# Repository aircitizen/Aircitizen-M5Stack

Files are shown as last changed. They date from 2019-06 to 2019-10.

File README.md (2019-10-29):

# m5stack

### Description

Here you'll find the CAD (STL+ F3d) for making your own shield, and the electronic shield (eagle + gerber file)

Component Name | Product link
------------ | -------------
M5 board |  https://amzn.to/2YmzmEy
Battery shield 700mAh  | https://amzn.to/2IX5oBG
Plantower PMSA003 | add link here.

 ###### Credit
Created by Vincent DUPUIS
with participation of :

Adel KHENICHE on Electronic production

Raphael BOYERO on 3D design.

#### Sources

Adafruit SHT31 | https://github.com/adafruit/Adafruit-SHT31-Sensor-Breakout-PCB

Adafruit Si7021 | https://learn.adafruit.com/adafruit-si7021-temperature-plus-humidity-sensor

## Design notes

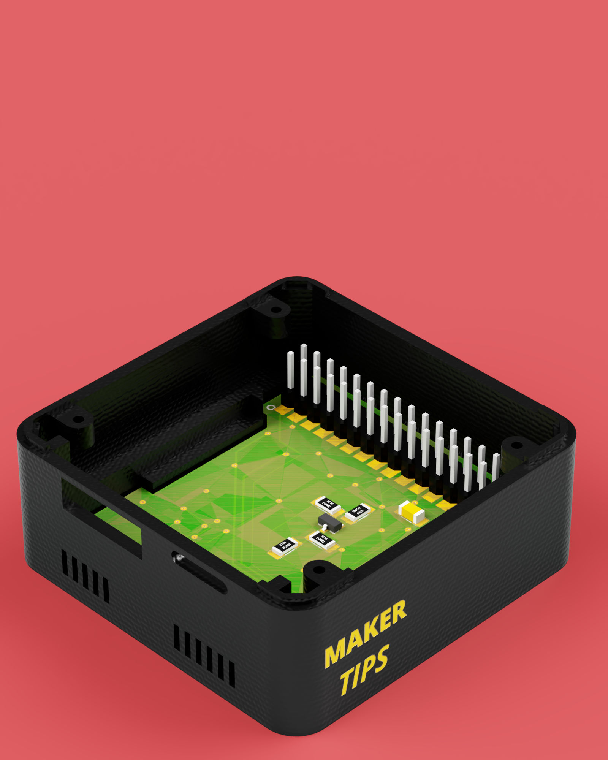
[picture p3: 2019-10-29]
SHIELDM5AIRCITIZEN_PROD_SANS_FOND_2019-Jul-20_07-20-32PM-000_CustomizedView6140740937.png

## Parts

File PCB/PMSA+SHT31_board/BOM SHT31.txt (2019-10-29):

Partlist exported from C:/Users/adelk/Documents/aircitizen2/Aircitizen-M5Stack/PCB/PMSA+SHT31_board/SHT31_2.sch at 15/07/2019 10:04

Part Value                 Device                Package     Description                                                             DK_ID          PROD_ID     P_NAME
C2   10uF                  CAP_CERAMIC_1206      _1206       Ceramic Capacitors                                                                                       
C13  10uF                  RES-US1206FAB         R1206FAB    Resistor (US Symbol)                                                                   CAP-11330         
CN2  CON_PINHD-2X15        CON_PINHD-2X15        2X15SMD                                                                                                              
Q3   MOSFET-NCHANNELBSS138 MOSFET-NCHANNELBSS138 SOT23-3     Common NMOSFET Parts                                                                   TRANS-00830 BSS138
R6   10K                   RESISTOR_1206MP       _1206MP     Resistors                                                                                                
R7   10K                   RESISTOR_1206MP       _1206MP     Resistors                                                                                                
R8   10K                   RESISTOR_1206MP       _1206MP     Resistors                                                                                                
R9   10K                   RESISTOR_1206MP       _1206MP     Resistors                                                                                                
R13  51                    RES-US1206FAB         R1206FAB    Resistor (US Symbol)                                                                   RES-12314         
R17  100                   RES-US1206FAB         R1206FAB    Resistor (US Symbol)                                                                                     
R18  100K                  RES-US1206FAB         R1206FAB    Resistor (US Symbol)                                                                                     
R19  82                    RES-US1206FAB         R1206FAB    Resistor (US Symbol)                                                    541-82.0CCT-ND                   
R20  22K                   RES-US1206FAB         R1206FAB    Resistor (US Symbol)                                                                                     
R21  82                    RES-US1206FAB         R1206FAB    Resistor (US Symbol)                                                    541-82.0CCT-ND                   
R22  47K                   RES-US1206FAB         R1206FAB    Resistor (US Symbol)                                                                                     
U$9  PLANTOWER             PLANTOWER             CONN                                                                                                                 
U2   SHT31-DIS             SHT3X                 SHT3X       SHT3x - Digital Temperature and Humidity Sensor                                                          
U3   MICS-4514             MICS-4514             MICS_10-SMD Metal oxide MEMS carbon monoxide (CO) and NOx sensor in an SMD package.                COMP-12310

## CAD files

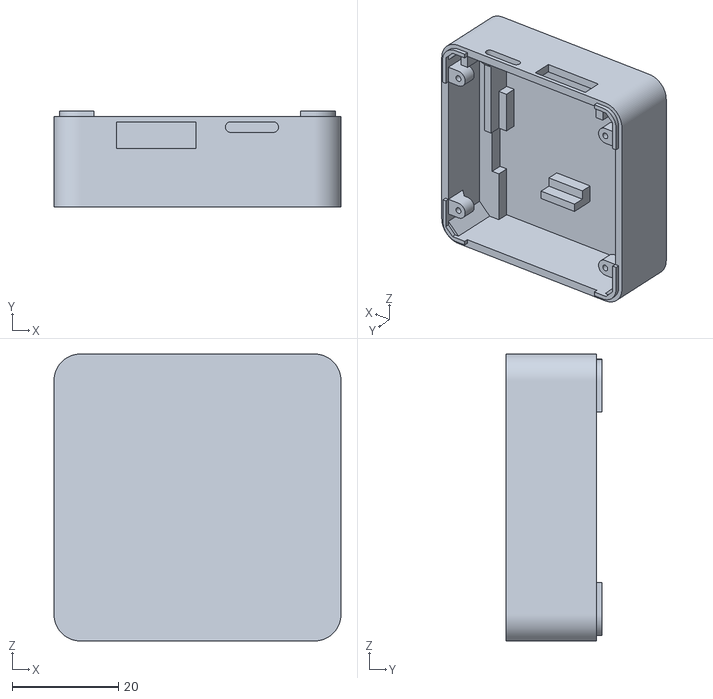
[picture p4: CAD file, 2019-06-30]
3D printing case/3D case.stl
54.0 x 18.0 x 54.0

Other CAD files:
3D printing case/SHIELDM5AIRCITIZEN v15.f3d

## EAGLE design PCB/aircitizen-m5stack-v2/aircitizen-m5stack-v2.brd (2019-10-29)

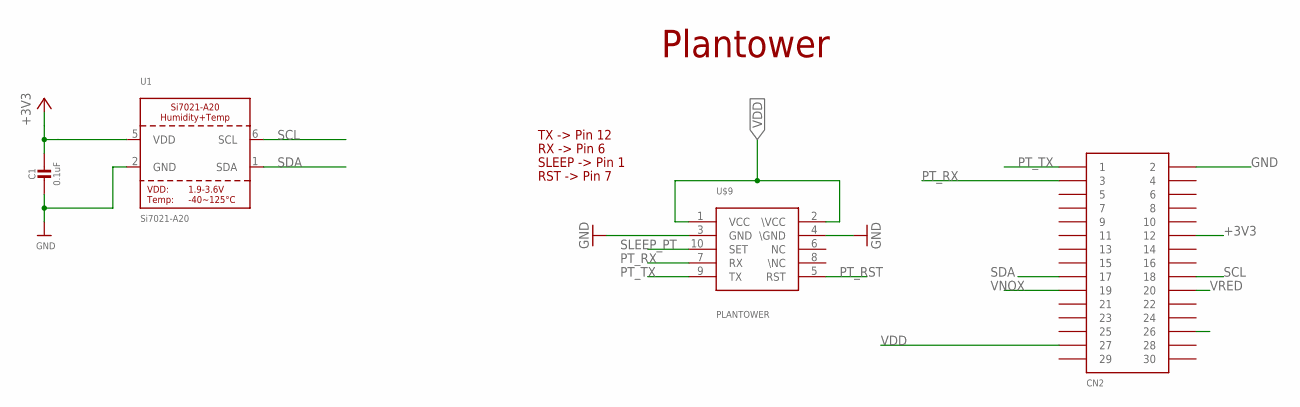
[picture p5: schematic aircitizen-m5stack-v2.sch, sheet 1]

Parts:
C1: 0.1uF; _1206
CN2: CON_PINHD-2X15; 2X15SMD
U1: Si7021-A20; DFN6_3X3_SI
U$9: PLANTOWER; CONN

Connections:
+3V3: C1.1, CN2.P$12 (12), U1.5 (VDD)
GND: C1.2, CN2.P$2 (2), U1.2 (GND), U$9.3 (GND), U$9.4 (\GND); also elsewhere on the board
PRE26: CN2.P$26 (26); also elsewhere on the board
PT_RST: U$9.5 (RST)
PT_RX: CN2.P$3 (3), U$9.7 (RX)
PT_TX: CN2.P$1 (1), U$9.9 (TX)
SCL: CN2.P$18 (18), U1.6 (SCL)
SDA: CN2.P$17 (17), U1.1 (SDA)
SLEEP_PT: U$9.10 (SET)
VDD: CN2.P$27 (27), U$9.1 (VCC), U$9.2 (\VCC); also elsewhere on the board
VNOX: CN2.P$19 (19); also elsewhere on the board
VRED: CN2.P$20 (20); also elsewhere on the board

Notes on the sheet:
Plantower
RX -> Pin 6
TX -> Pin 12
SLEEP -> Pin 1
RST -> Pin 7

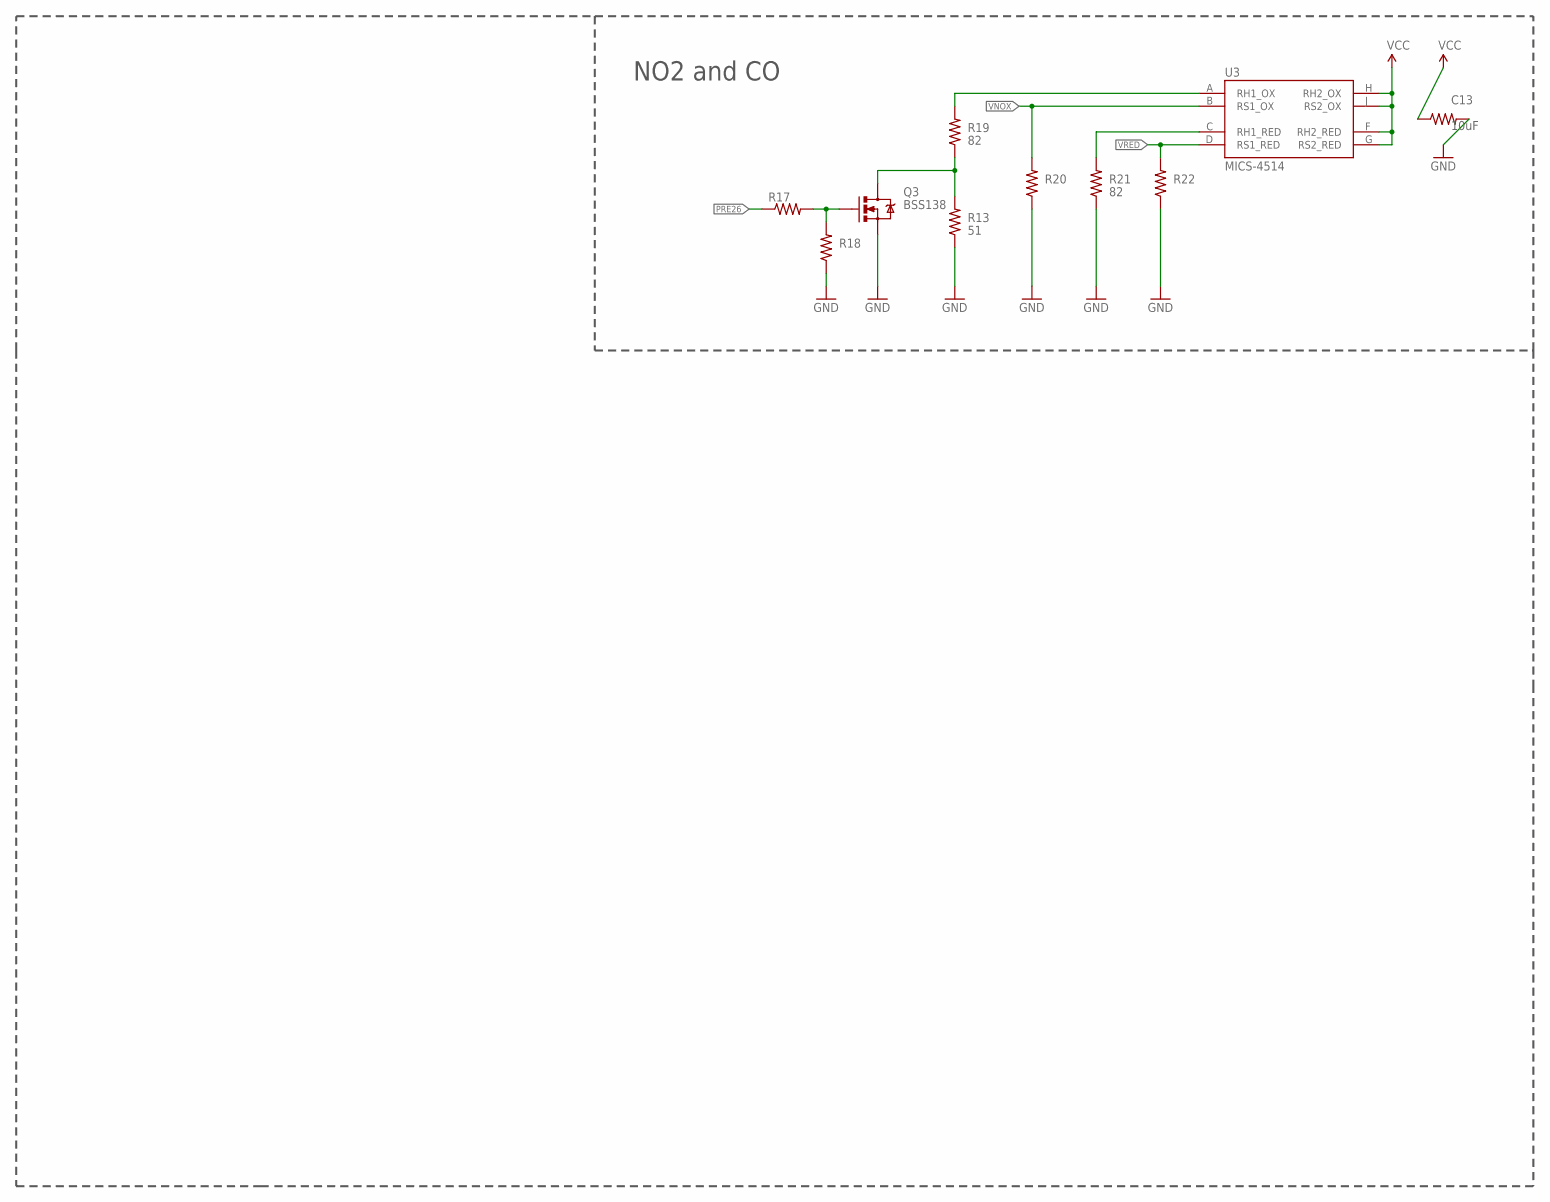
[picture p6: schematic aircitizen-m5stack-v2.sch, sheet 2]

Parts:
C13: 10uF; R1206FAB
Q3: MOSFET-NCHANNELBSS138; SOT23-3
R13: 51; R1206FAB
R17: 100; R1206FAB
R18: 100K; R1206FAB
R19, R21: 82; R1206FAB
R20: 22K; R1206FAB
R22: 47K; R1206FAB
U3: MICS-4514; MICS_10-SMD

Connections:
GND: C13.2, Q3.2 (S), R13.1, R18.1, R20.1, R21.1, R22.1; also elsewhere on the board
unnamed: Q3.3 (D), R13.2, R19.1
unnamed: Q3.1 (G), R17.2, R18.2
unnamed: R19.2, U3.A (RH1_OX)
unnamed: R21.2, U3.C (RH1_RED)
PRE26: R17.1; also elsewhere on the board
VDD: C13.1, U3.F (RH2_RED), U3.G (RS2_RED), U3.H (RH2_OX), U3.J (RS2_OX); also elsewhere on the board
VNOX: R20.2, U3.B (RS1_OX); also elsewhere on the board
VRED: R22.2, U3.D (RS1_RED); also elsewhere on the board

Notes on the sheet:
NO2 and CO

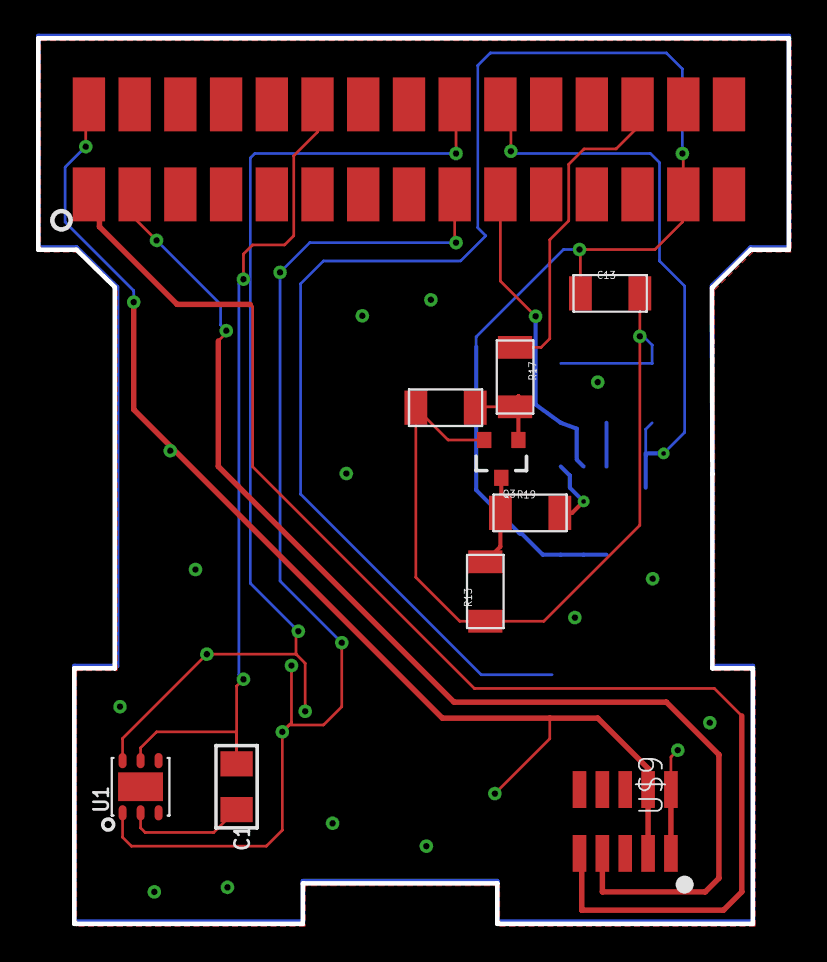
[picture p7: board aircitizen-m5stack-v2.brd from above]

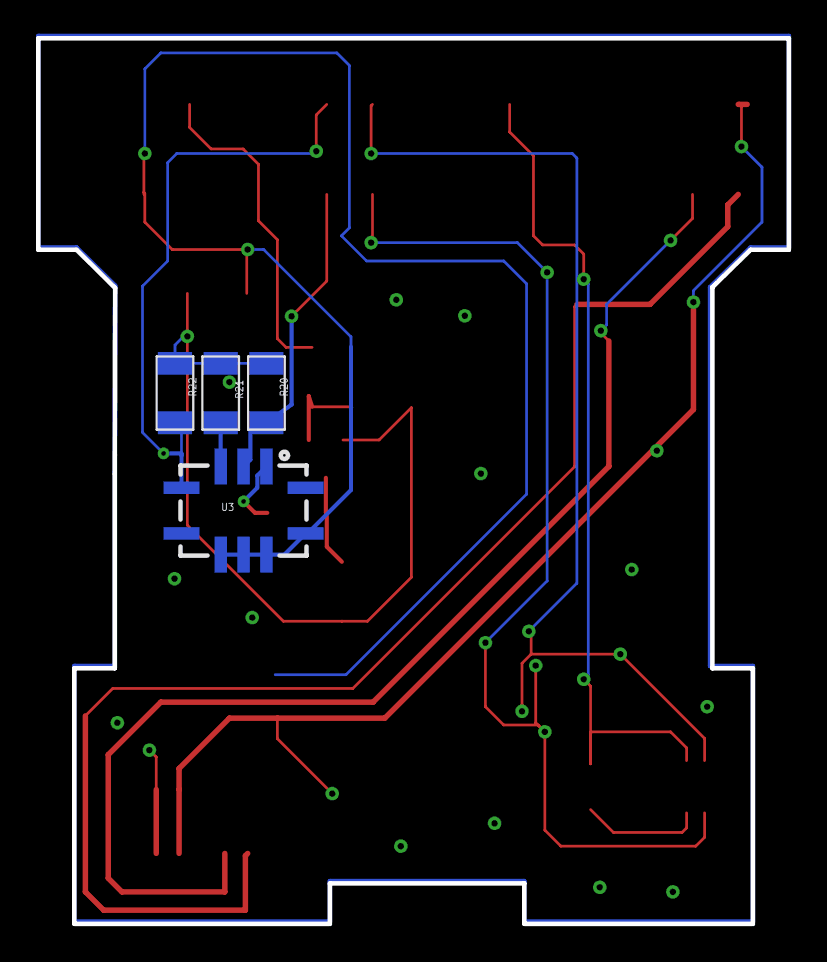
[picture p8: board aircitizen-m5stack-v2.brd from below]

Board: 2 copper layers, 41.7 x 49.2 mm, 14 parts (4 on the bottom side), 14 nets.

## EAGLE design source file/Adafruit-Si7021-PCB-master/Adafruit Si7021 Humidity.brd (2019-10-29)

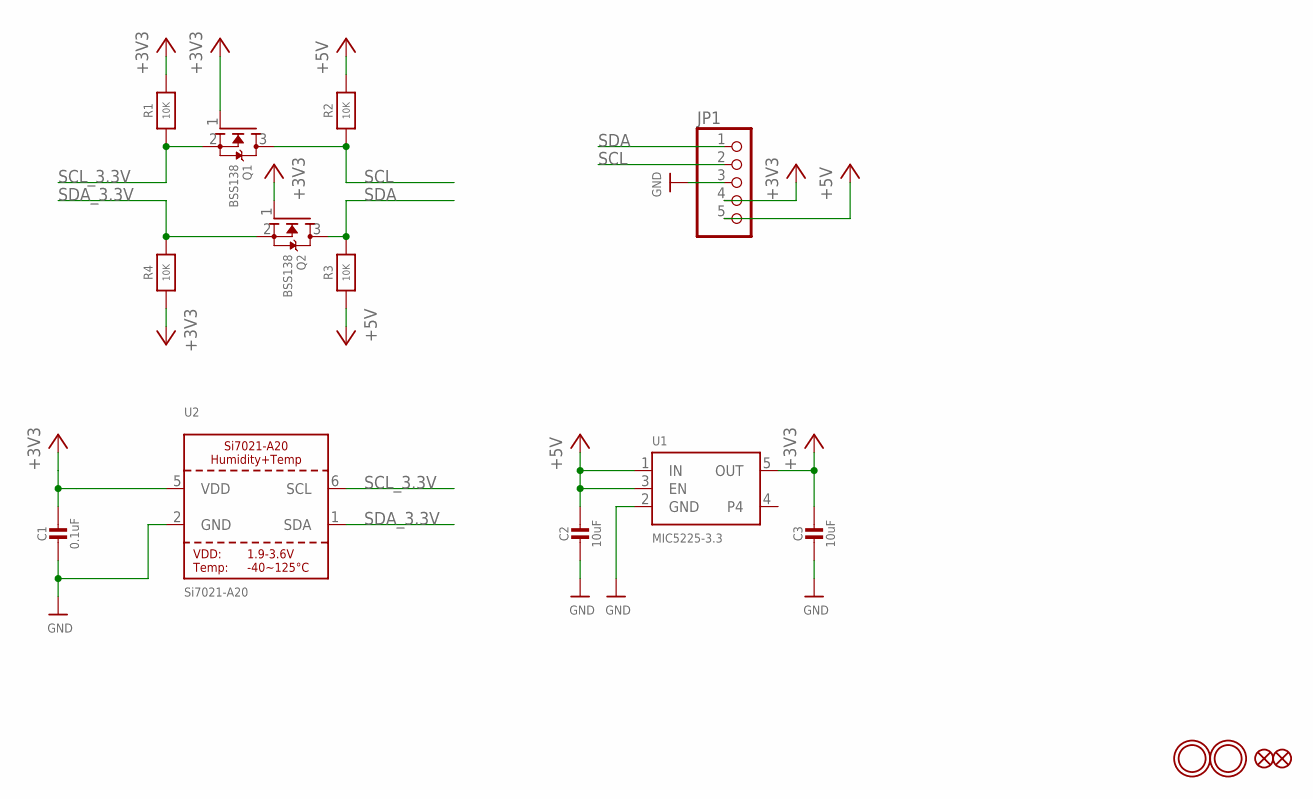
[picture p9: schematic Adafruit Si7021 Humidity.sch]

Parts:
C1: 0.1uF; 0805-NO
C2, C3: 10uF; 0805-NO
FID1, FID2: FIDUCIAL""; FIDUCIAL_1MM
JP1: HEADER-1X570MIL; 1X05_ROUND_70
Q1, Q2: BSS138; SOT23-WIDE
R1, R2, R3, R4: 10K; 0805-NO
U1: MIC5225-3.3; SOT23-5
U2: Si7021-A20; DFN6_3X3_SI
U$6, U$7: MOUNTINGHOLE2.5; MOUNTINGHOLE_2.5_PLATED

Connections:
+3V3: C1.1, C3.1, JP1.4, Q1.1 (G), Q2.1 (G), R1.2, R4.1, U1.5 (OUT), U2.5 (VDD)
GND: C1.2, C2.2, C3.2, JP1.3, U1.2 (GND), U2.2 (GND)
SCL: JP1.2, Q1.3 (D), R2.1
SCL_3.3V: Q1.2 (S), R1.1, U2.6 (SCL)
SDA: JP1.1, Q2.3 (D), R3.2
SDA_3.3V: Q2.2 (S), R4.2, U2.1 (SDA)
VIN: C2.1, JP1.5, R2.2, R3.1, U1.1 (IN), U1.3 (EN)

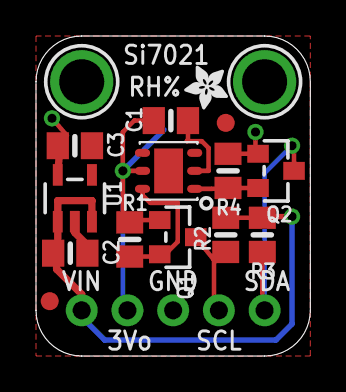
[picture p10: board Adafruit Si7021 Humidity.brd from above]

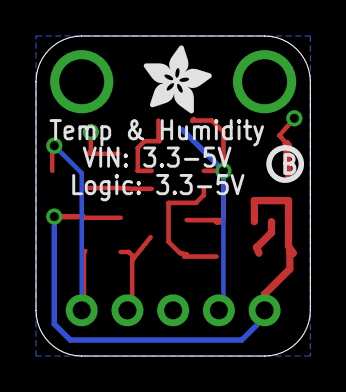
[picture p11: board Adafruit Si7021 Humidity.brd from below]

Board: 2 copper layers, 15.2 x 17.8 mm, 19 parts (2 on the bottom side), 7 nets.

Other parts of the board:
U$1: ADAFRUIT_2.5MM
U$9: PCBFEAT-REV-040
U$10: ADAFRUIT_3.5MM

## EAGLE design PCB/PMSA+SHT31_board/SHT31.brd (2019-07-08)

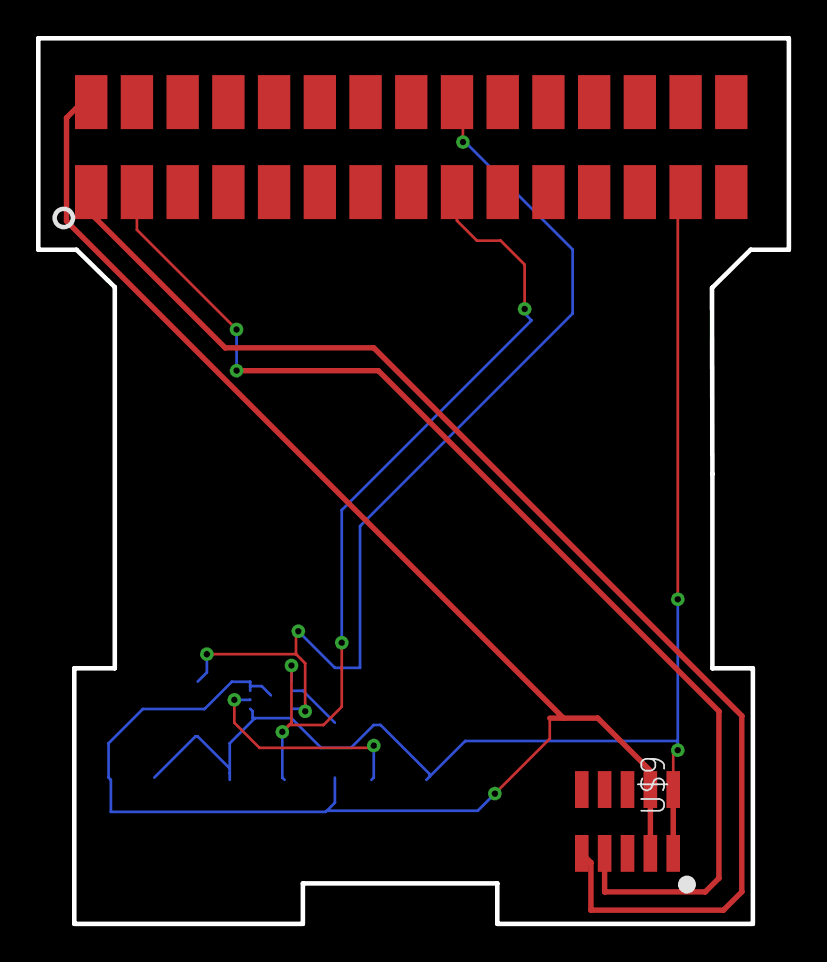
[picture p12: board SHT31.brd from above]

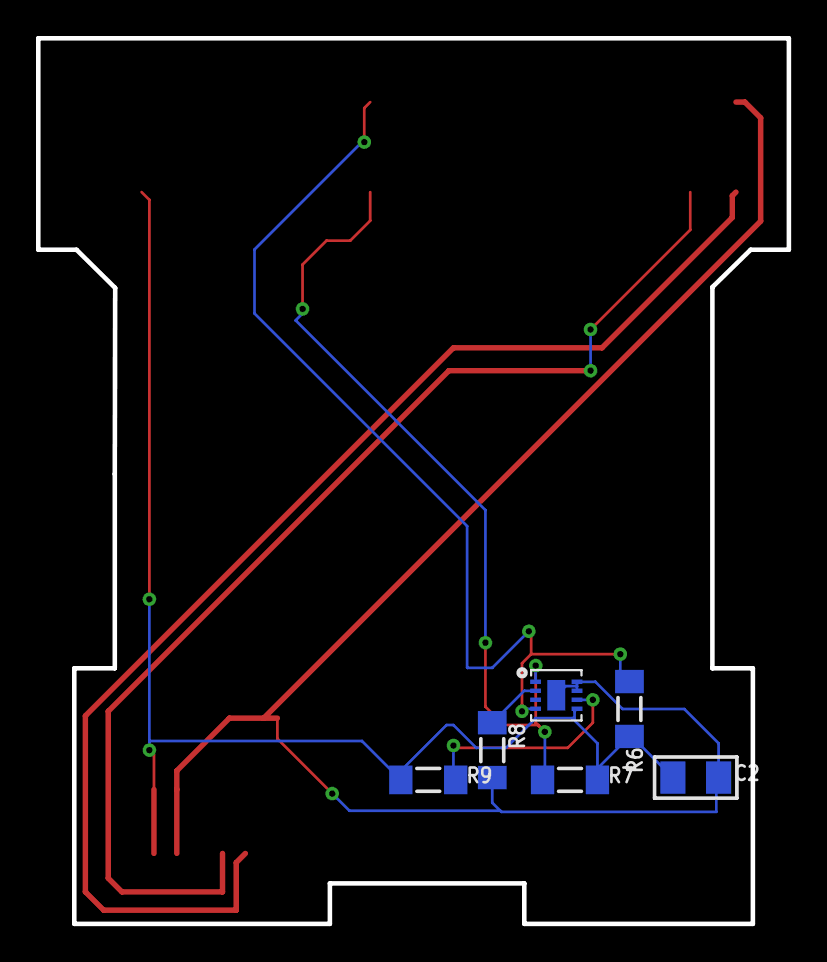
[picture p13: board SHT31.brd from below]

Board: 2 copper layers, 41.7 x 49.2 mm, 8 parts (6 on the bottom side), 8 nets.

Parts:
C2: 10uF; _1206
CN2: CON_PINHD-2X15; 2X15SMD
R6, R7, R8, R9: 10K; _1206MP
U2: SHT31-DIS; SHT3X
U$9: PLANTOWER; CONN

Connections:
ADDR: R8.1, U2.2
GND: C2.2, CN2.P$2, R8.2, U2.7, U2.8, U2.THERMAL, U$9.3, U$9.4
PT_RX: CN2.P$3, U$9.7
PT_TX: CN2.P$1, U$9.9
RST: R9.2, U2.6
SCL: CN2.P$18, R6.1, U2.4
SDA: CN2.P$17, R7.1, U2.1
VDD: C2.1, CN2.P$27, R6.2, R7.2, R9.1, U2.5, U$9.1, U$9.2

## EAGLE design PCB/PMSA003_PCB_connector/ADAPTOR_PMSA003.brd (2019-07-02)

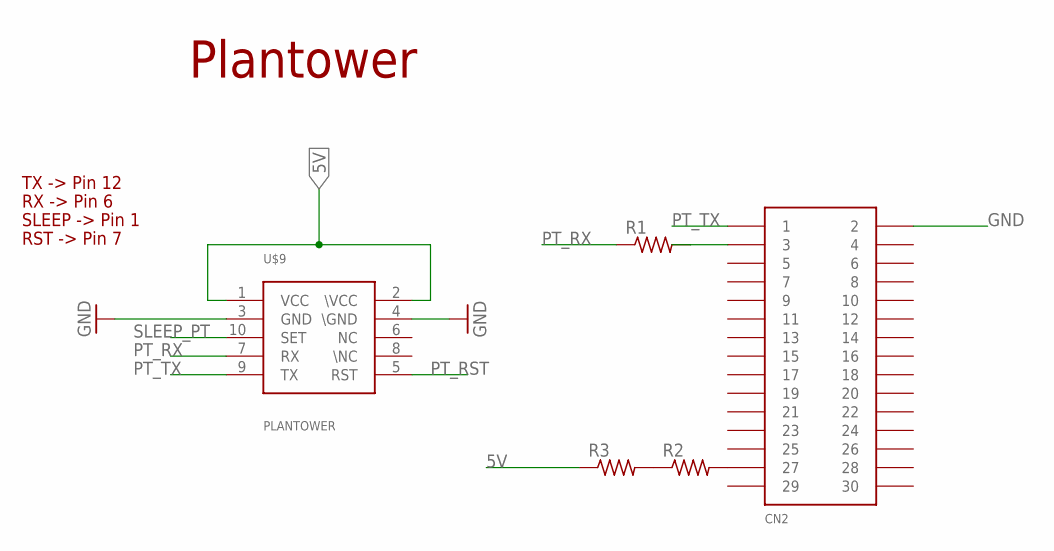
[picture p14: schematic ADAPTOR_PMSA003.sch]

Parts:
CN2: CON_PINHD-2X15; 2X15SMD
R1, R2, R3: RES-US1206FAB; R1206FAB
U$9: PLANTOWER; CONN

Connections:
5V: R3.1, U$9.1 (VCC), U$9.2 (\VCC)
DELETE: CN2.P$3 (3), R1.2
GND: CN2.P$2 (2), U$9.3 (GND), U$9.4 (\GND)
unnamed: CN2.P$27 (27), R2.2
unnamed: R2.1, R3.2
PT_RST: U$9.5 (RST)
PT_RX: R1.1, U$9.7 (RX)
PT_TX: CN2.P$1 (1), U$9.9 (TX)
SLEEP_PT: U$9.10 (SET)

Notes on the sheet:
Plantower
RX -> Pin 6
TX -> Pin 12
SLEEP -> Pin 1
RST -> Pin 7

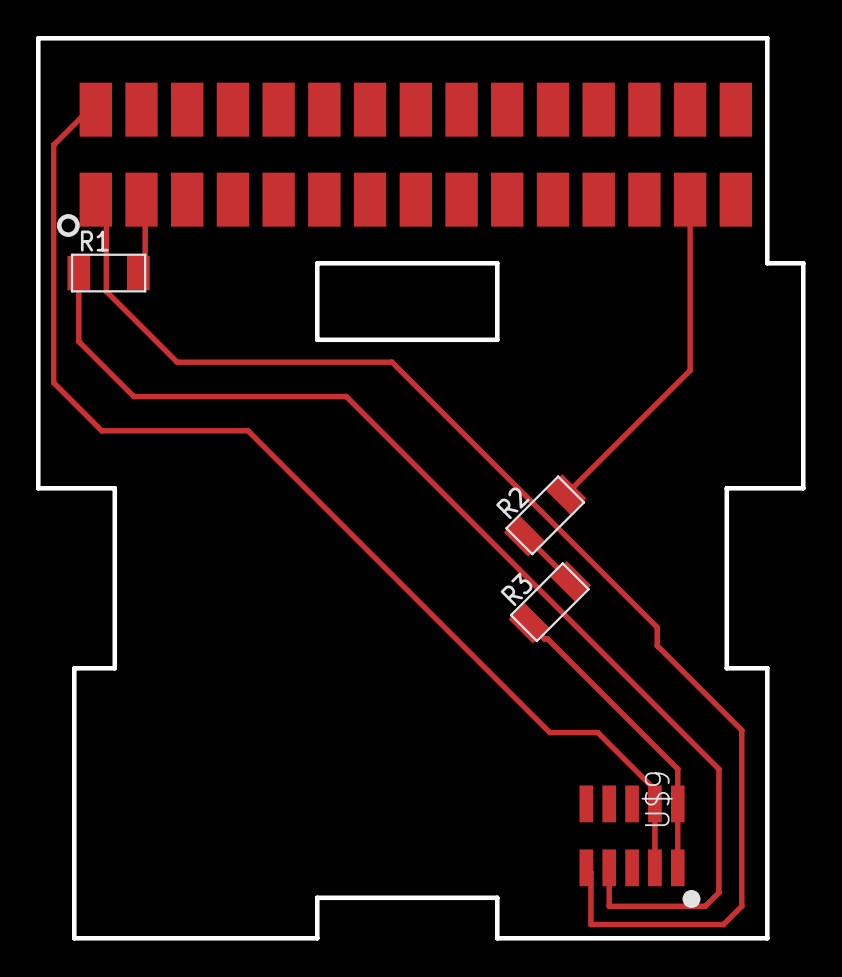
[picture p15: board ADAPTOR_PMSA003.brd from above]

Board: 2 copper layers, 42.5 x 50.0 mm, 5 parts (0 on the bottom side), 7 nets.

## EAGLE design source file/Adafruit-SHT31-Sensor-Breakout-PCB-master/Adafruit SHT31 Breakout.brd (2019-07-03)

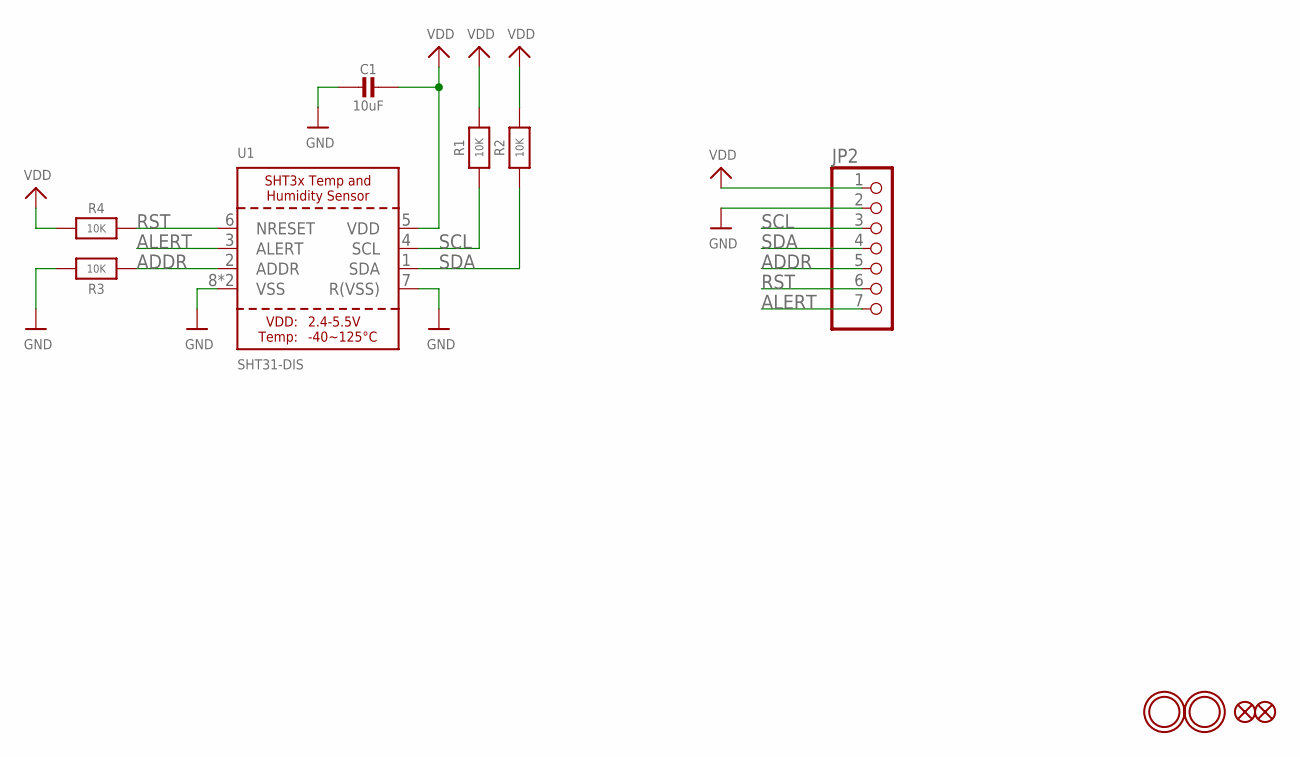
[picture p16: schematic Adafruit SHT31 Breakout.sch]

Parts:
C1: 10uF; 0805-NO
FID2, FID3: FIDUCIAL""; FIDUCIAL_1MM
JP2: HEADER-1X770MIL; 1X07_ROUND_70
R1, R2, R4: 10K; 0805-NO
R3: 10K; _0805MP
U1: SHT31-DIS; SHT3X
U$1, U$2: MOUNTINGHOLE2.5; MOUNTINGHOLE_2.5_PLATED

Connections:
ADDR: JP2.5, R3.1, U1.2 (ADDR)
ALERT: JP2.7, U1.3 (ALERT)
GND: C1.2, JP2.2, R3.2, U1.7 (R(VSS)), U1.8 (VSS), U1.THERMAL (VSS)
RST: JP2.6, R4.2, U1.6 (NRESET)
SCL: JP2.3, R1.1, U1.4 (SCL)
SDA: JP2.4, R2.1, U1.1 (SDA)
VDD: C1.1, JP2.1, R1.2, R2.2, R4.1, U1.5 (VDD)


Board: 2 copper layers, 17.8 x 12.7 mm, 13 parts (1 on the bottom side), 7 nets.

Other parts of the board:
U$11: PCBFEAT-REV-040
U$13: ADAFRUIT_2.5MM

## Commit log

2019-06-30 test upload
    [3D case.stl, SHIELDM5AIRCITIZEN v15.f3d, m5stack-2sided-pinheader.brd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]
2019-07-02 clean up and add pcb
    [ADAPTOR_PMSA003.brd, ADAPTOR_PMSA003.sch, m5stack-2sided-pinheader.brd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]
2019-07-03 adding adafruit source file
    [Adafruit SHT31 Breakout.brd, Adafruit SHT31 Breakout.sch]
2019-07-08 cp sht31
    [SHT31_2.brd, SHT31_2.sch]
2019-07-08 insertion NOX & CO Captor
    [SHT31.brd, SHT31.sch, SHT31_2.brd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]
2019-07-08 add amigo proto
    [M5amigo.brd, M5amigo.sch]
2019-07-08 pcbV2 ready to go!
    [SHT31_2.brd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]
2019-10-29 change Temp and RH sensor
    [copper_bottom.gbr, copper_top.gbr, drill_1_16.xln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]
2019-10-29 add new pcb
2019-10-29 add pcvb
    [aircitizen-m5stack-v2.brd, aircitizen-m5stack-v2.sch]
2019-10-29 add source file
    [Adafruit Si7021 Humidity.brd, Adafruit Si7021 Humidity.sch]
2019-10-29 Nouvel version pcb V2
    [SHT31_2.brd, SHT31_2.sch, aircitizen-m5stack-v2.brd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]
2019-10-29 version pcb #2

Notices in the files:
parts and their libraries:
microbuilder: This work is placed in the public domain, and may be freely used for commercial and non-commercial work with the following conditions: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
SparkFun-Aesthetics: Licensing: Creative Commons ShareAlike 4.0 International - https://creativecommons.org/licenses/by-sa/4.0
